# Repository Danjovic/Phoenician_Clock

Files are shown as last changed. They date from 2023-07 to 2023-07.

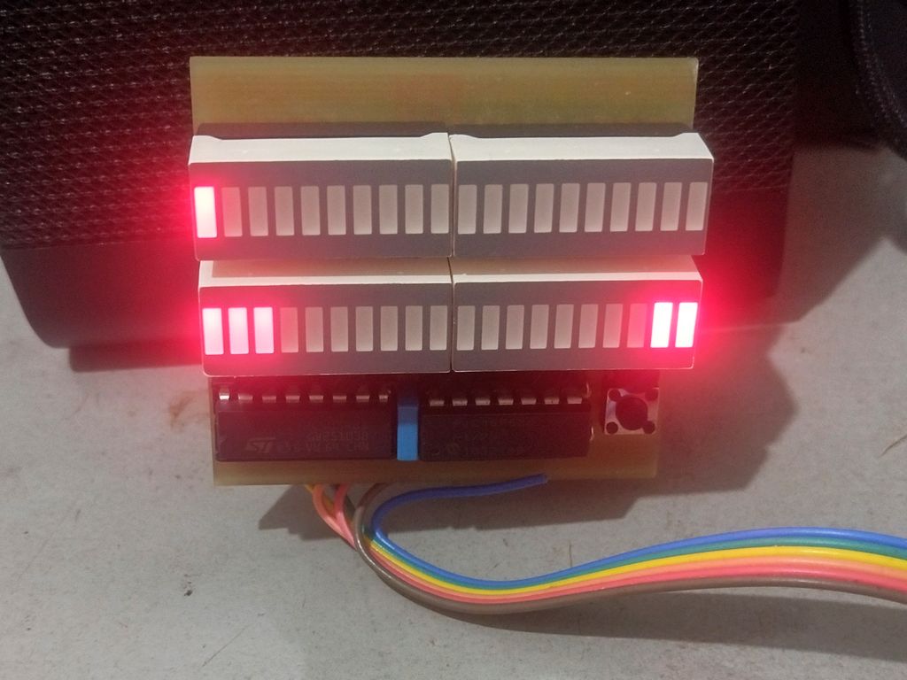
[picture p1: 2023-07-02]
doc/IMG_20230702_103354856_HDR.jpg

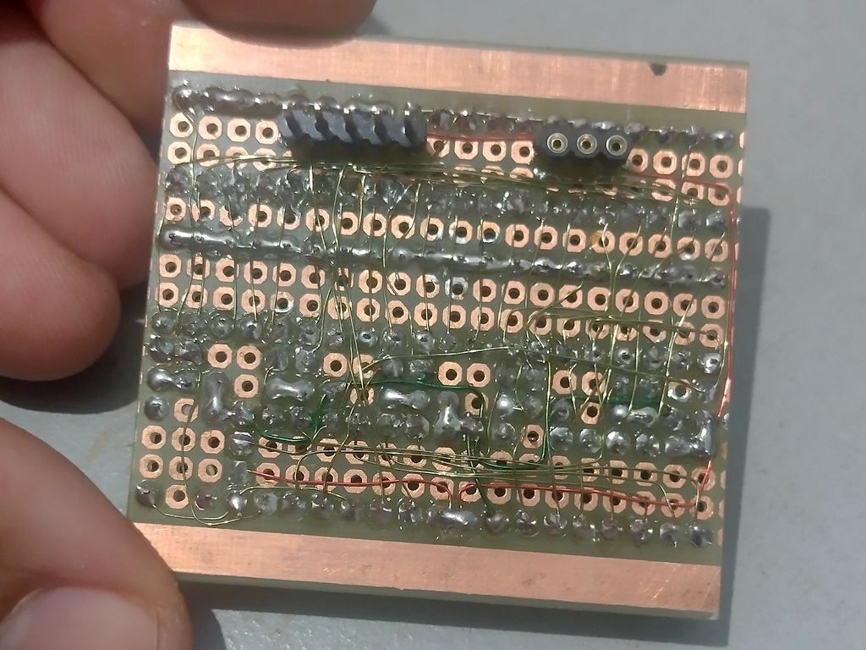
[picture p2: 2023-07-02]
doc/IMG_20230629_204115597.jpg

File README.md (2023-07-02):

# Phoenician_Clock
Digital clock with a LED bargraph display using Phoenician notation for individual digits.

## Introduction
Eevery digit of the (decimal) is displayed as a sequence of lit/unlit bars equivalent to the phoenician representation of digits 1 to 9. 

| Decimal | Phoenician |
|:---:|:---:|
| 1 | \| |
| 2 | \|\| |
| 3 | \|\|\| |
| 4 | \| \|\|\| |
| 5 | \|\| \|\|\| |
| 6 |  \|\|\|  \|\|\| |
| 7 | \| \|\|\| \|\|\| |
| 8 | \|\| \|\|\| \|\|\| |
| 9 | \|\|\| \|\|\| \|\|\| |

#### Dealing wiht the zero

The Phoenicians do not have a zero but it can be displayed as no segment lit. It is necessary, though, to justify the digits to the left or to the right to differentiate 10 from 01

| minute | Display |
|:---:|:---:|
| 05 | --------------\|\| \|\|\| |
| 50 | \|\| \|\|\|-------------- |

### How many bars ?
The biggest number to be displayed is 59. It takes at least 19 bars, being 6 for the digit 5 and 11 bars for the digit 9 plus two bars of spacing.
  
\|\|-\|\|\|--\|\|\|-\|\|\|-\|\|\|   

A couple of 10 segment Bargraph modules will be enough to represent the time.

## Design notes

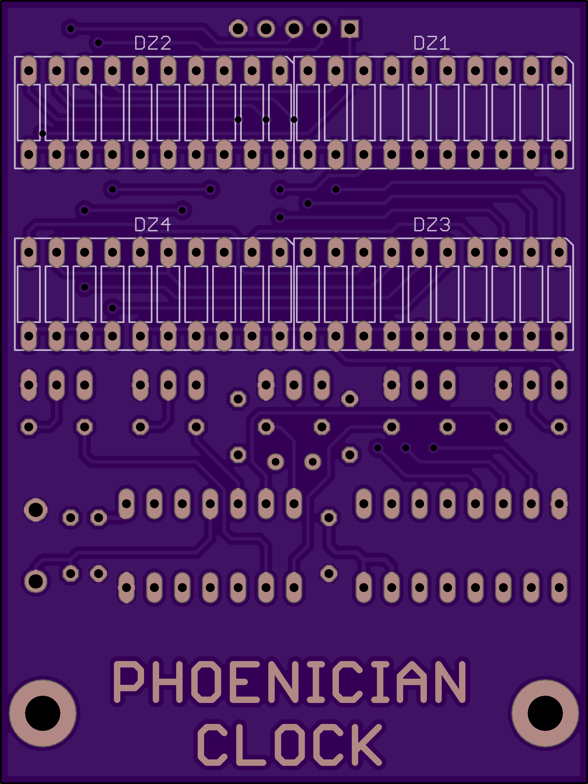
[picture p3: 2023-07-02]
doc/08815e3fb104f50b54aa8fa264df31f2.png

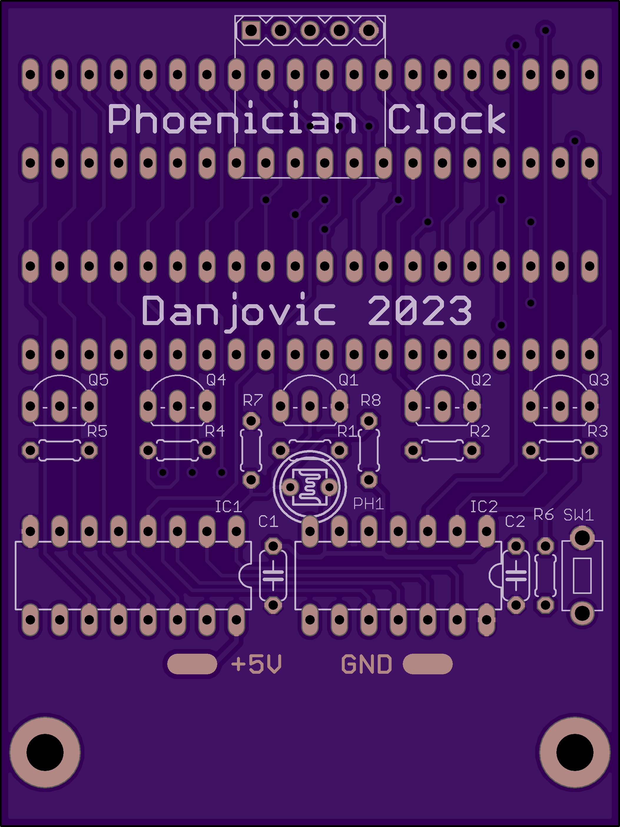
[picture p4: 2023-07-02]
doc/3a418aa845c536e2b2829bd620c7e151.png

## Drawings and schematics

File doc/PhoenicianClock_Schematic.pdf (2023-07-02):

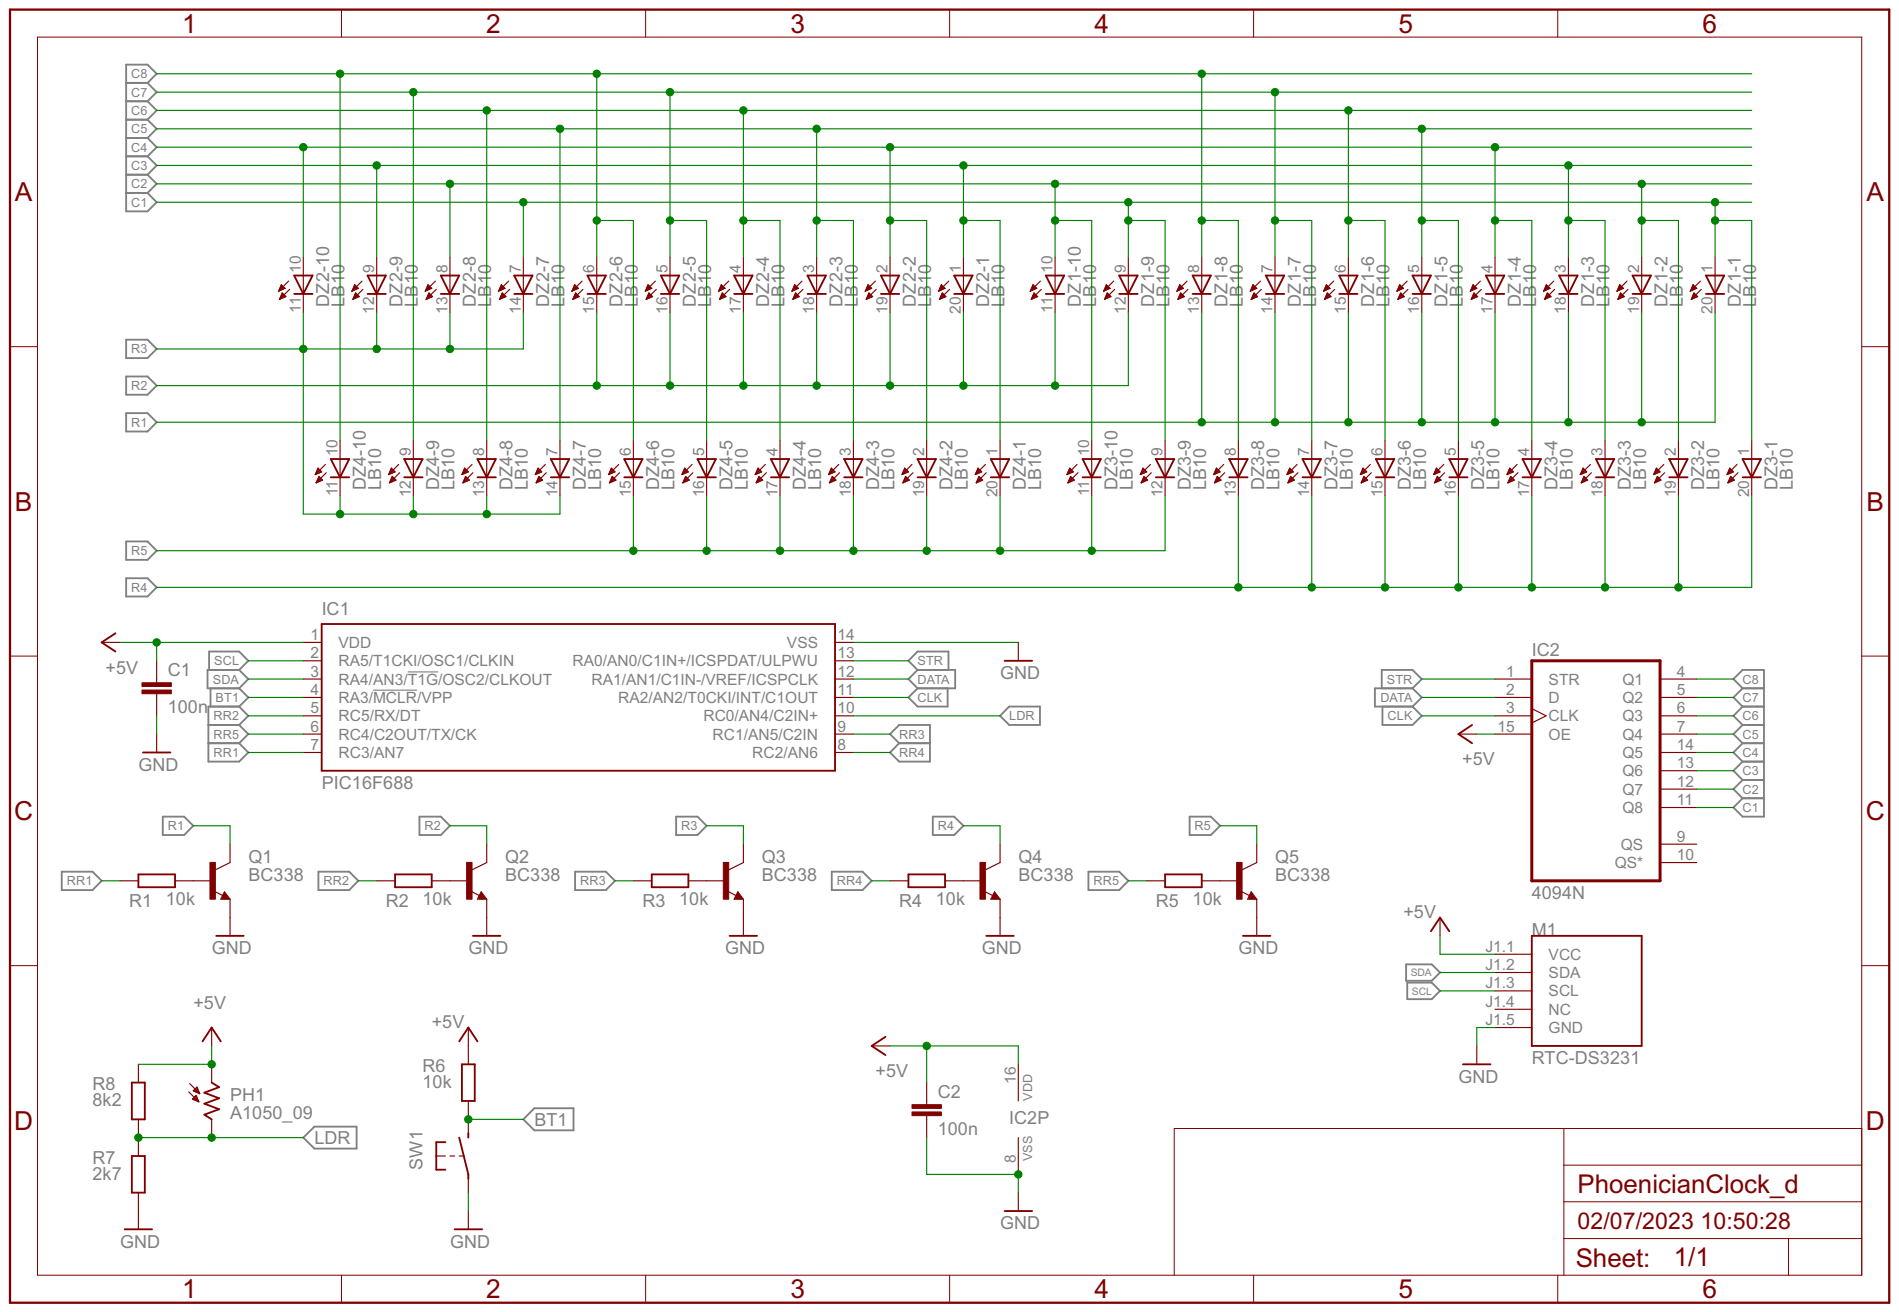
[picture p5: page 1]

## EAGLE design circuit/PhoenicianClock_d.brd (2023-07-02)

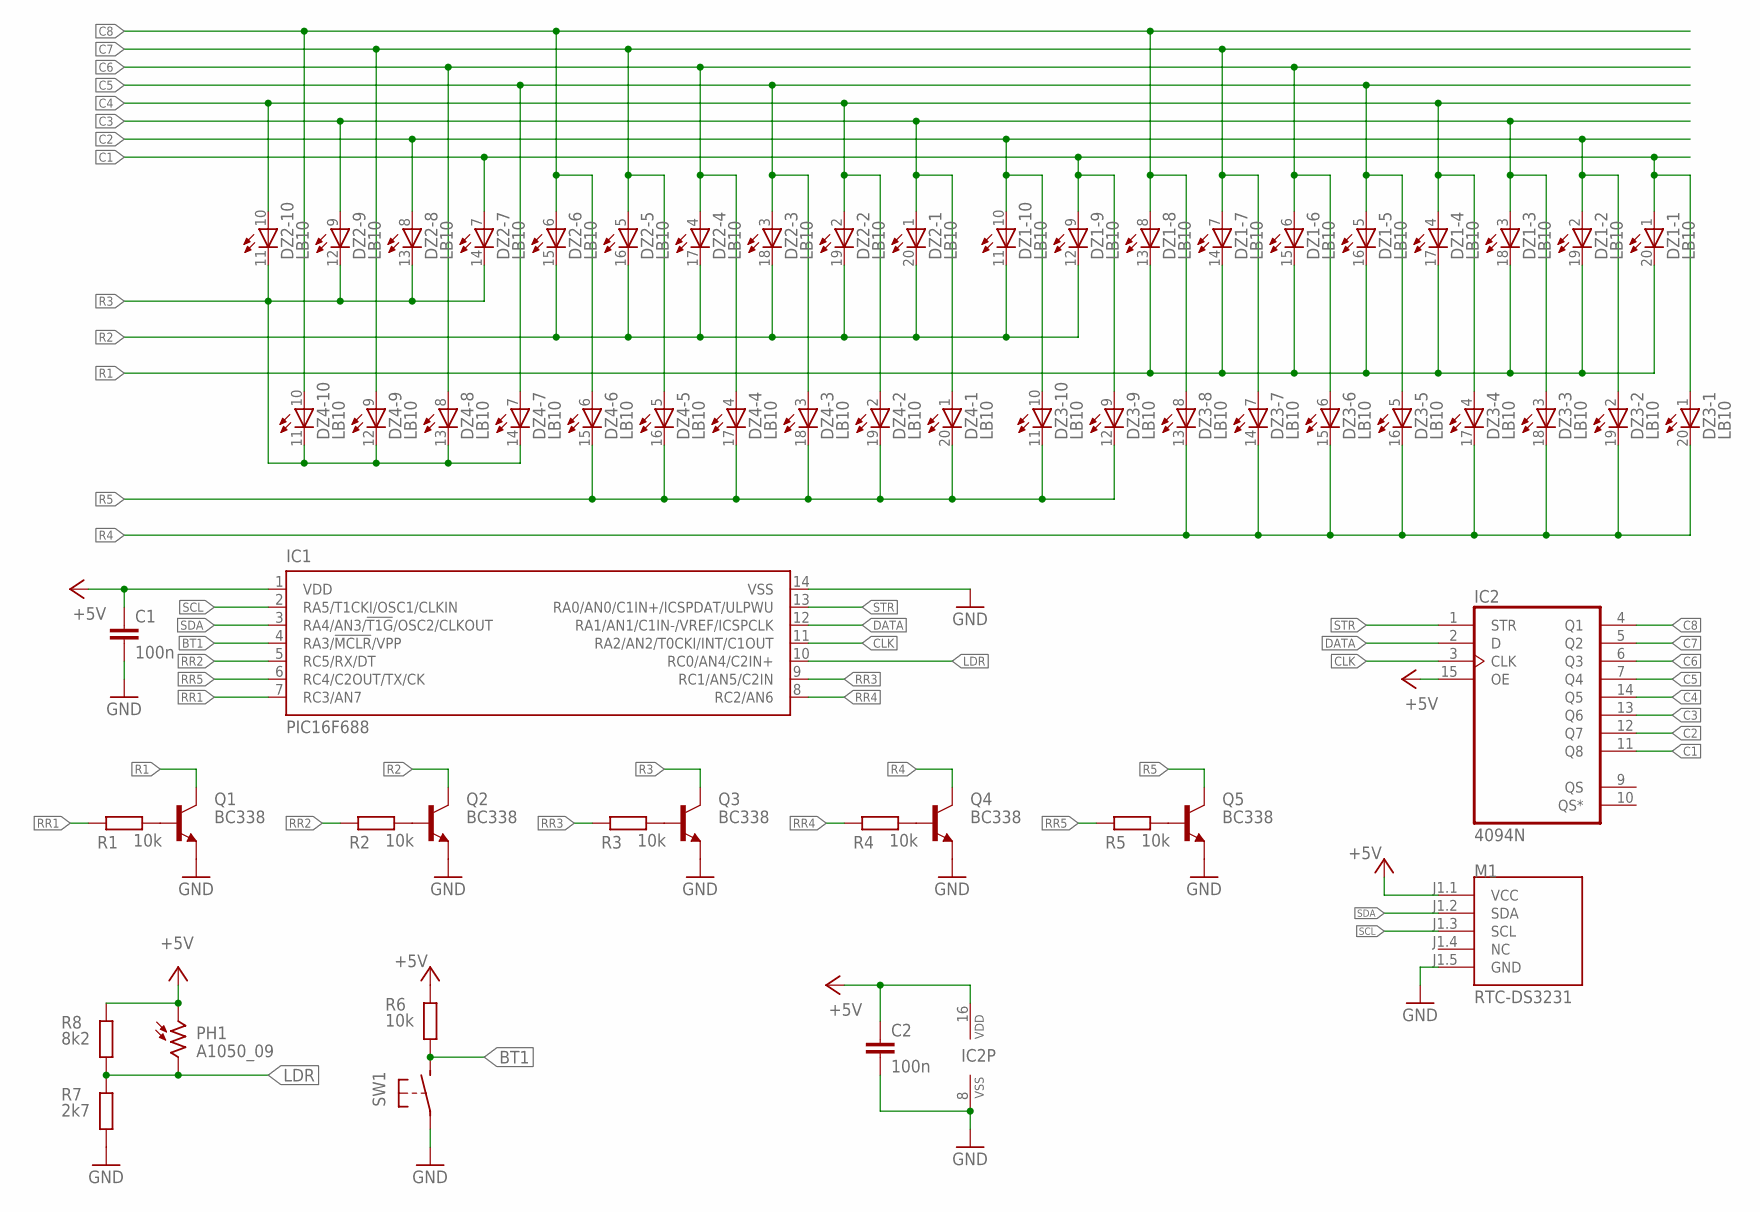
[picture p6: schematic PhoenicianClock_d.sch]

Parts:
C1, C2: 100n; C050-024X044
DZ1, DZ2, DZ3, DZ4: LB10
IC1: PIC16F688; DIL14
IC2: 4094N; DIL16
M1: RTC-DS3231; RTC-DS3231_SMALL
PH1: A1050_09; T0-46-A10XX
Q1, Q2, Q3, Q4, Q5: BC338; TO92-EBC
R1, R2, R3, R4, R5, R6: 10k; 0204/5
R7: 2k7; 0204/5
R8: 8k2; 0204/5
SW1: MINISPDT; 2PST_MINI

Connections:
+5V: C1.1, C2.1, IC1.1 (VDD), IC2.15 (OE), IC2.16 (VDD), M1.J1.1 (VCC), PH1.1, R6.2, R8.2
BT1: IC1.4 (RA3/!MCLR!/VPP), R6.1, SW1.P$2 (S)
C1: DZ1.1 (A), DZ1.9 (A), DZ2.7 (A), DZ3.1 (A), DZ3.9 (A), IC2.11 (Q8)
C2: DZ1.2 (A), DZ1.10 (A), DZ2.8 (A), DZ3.2 (A), DZ3.10 (A), IC2.12 (Q7)
C3: DZ1.3 (A), DZ2.1 (A), DZ2.9 (A), DZ3.3 (A), DZ4.1 (A), IC2.13 (Q6)
C4: DZ1.4 (A), DZ2.2 (A), DZ2.10 (A), DZ3.4 (A), DZ4.2 (A), IC2.14 (Q5)
C5: DZ1.5 (A), DZ2.3 (A), DZ3.5 (A), DZ4.3 (A), DZ4.7 (A), IC2.7 (Q4)
C6: DZ1.6 (A), DZ2.4 (A), DZ3.6 (A), DZ4.4 (A), DZ4.8 (A), IC2.6 (Q3)
C7: DZ1.7 (A), DZ2.5 (A), DZ3.7 (A), DZ4.5 (A), DZ4.9 (A), IC2.5 (Q2)
C8: DZ1.8 (A), DZ2.6 (A), DZ3.8 (A), DZ4.6 (A), DZ4.10 (A), IC2.4 (Q1)
CLK: IC1.11 (RA2/AN2/T0CKI/INT/C1OUT), IC2.3 (CLK)
DATA: IC1.12 (RA1/AN1/C1IN-/VREF/ICSPCLK), IC2.2 (D)
GND: C1.2, C2.2, IC1.14 (VSS), IC2.8 (VSS), M1.J1.5 (GND), Q1.E, Q2.E, Q3.E, Q4.E, Q5.E, R7.1, SW1.P$1
LDR: IC1.10 (RC0/AN4/C2IN+), PH1.2, R7.2, R8.1
unnamed: Q1.B, R1.2
unnamed: Q2.B, R2.2
unnamed: Q3.B, R3.2
unnamed: Q4.B, R4.2
unnamed: Q5.B, R5.2
R1: DZ1.13 (C), DZ1.14 (C), DZ1.15 (C), DZ1.16 (C), DZ1.17 (C), DZ1.18 (C), DZ1.19 (C), DZ1.20 (C), Q1.C
R2: DZ1.11 (C), DZ1.12 (C), DZ2.15 (C), DZ2.16 (C), DZ2.17 (C), DZ2.18 (C), DZ2.19 (C), DZ2.20 (C), Q2.C
R3: DZ2.11 (C), DZ2.12 (C), DZ2.13 (C), DZ2.14 (C), DZ4.11 (C), DZ4.12 (C), DZ4.13 (C), DZ4.14 (C), Q3.C
R4: DZ3.13 (C), DZ3.14 (C), DZ3.15 (C), DZ3.16 (C), DZ3.17 (C), DZ3.18 (C), DZ3.19 (C), DZ3.20 (C), Q4.C
R5: DZ3.11 (C), DZ3.12 (C), DZ4.15 (C), DZ4.16 (C), DZ4.17 (C), DZ4.18 (C), DZ4.19 (C), DZ4.20 (C), Q5.C
RR1: IC1.7 (RC3/AN7), R1.1
RR2: IC1.5 (RC5/RX/DT), R2.1
RR3: IC1.9 (RC1/AN5/C2IN), R3.1
RR4: IC1.8 (RC2/AN6), R4.1
RR5: IC1.6 (RC4/C2OUT/TX/CK), R5.1
SCL: IC1.2 (RA5/T1CKI/OSC1/CLKIN), M1.J1.3 (SCL)
SDA: IC1.3 (RA4/AN3/!T1G!/OSC2/CLKOUT), M1.J1.2 (SDA)
STR: IC1.13 (RA0/AN0/C1IN+/ICSPDAT/ULPWU), IC2.1 (STR)

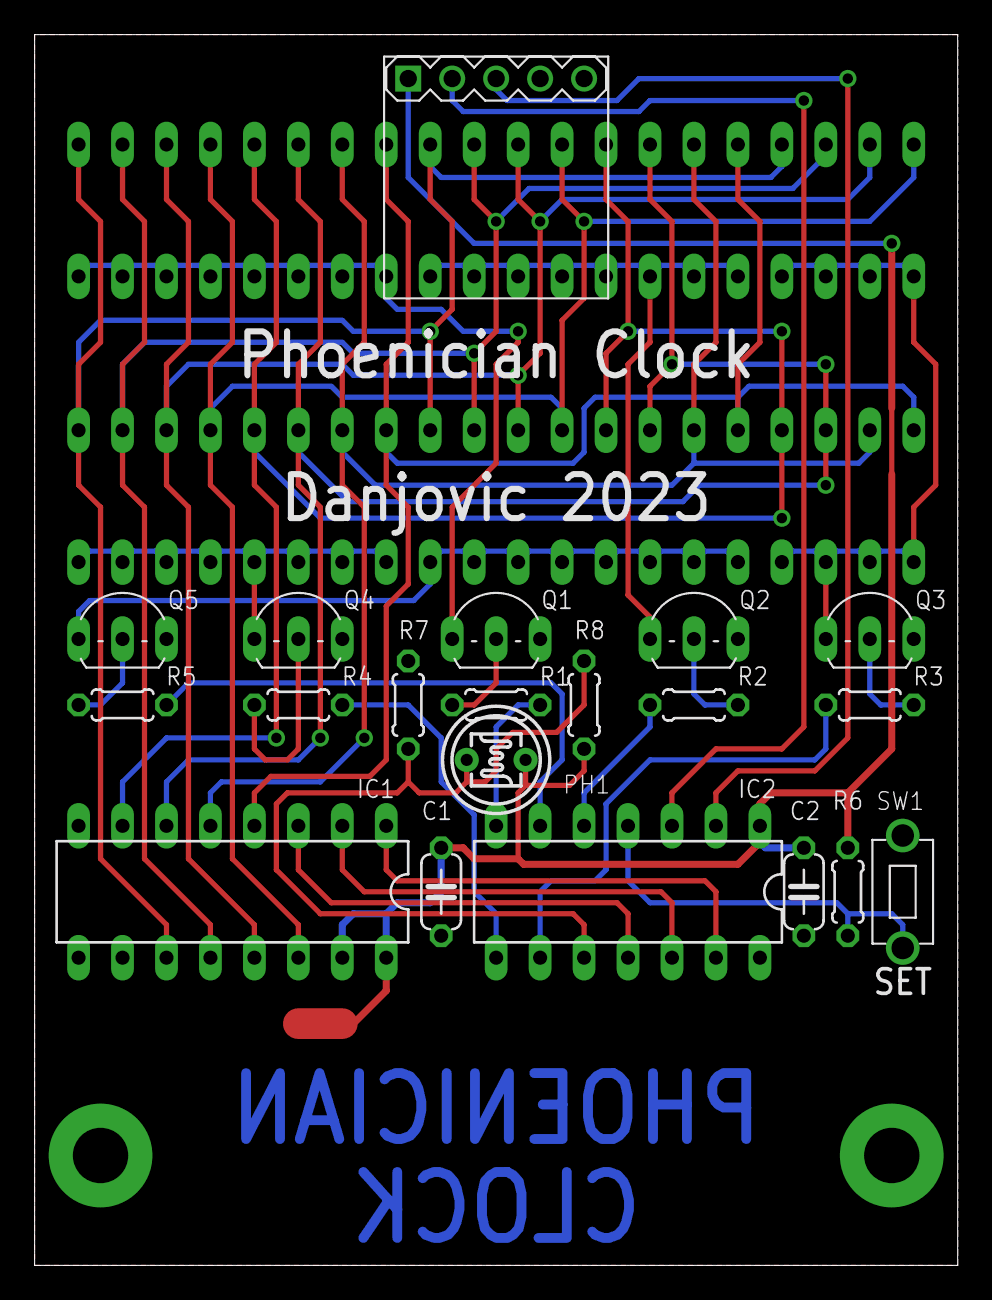
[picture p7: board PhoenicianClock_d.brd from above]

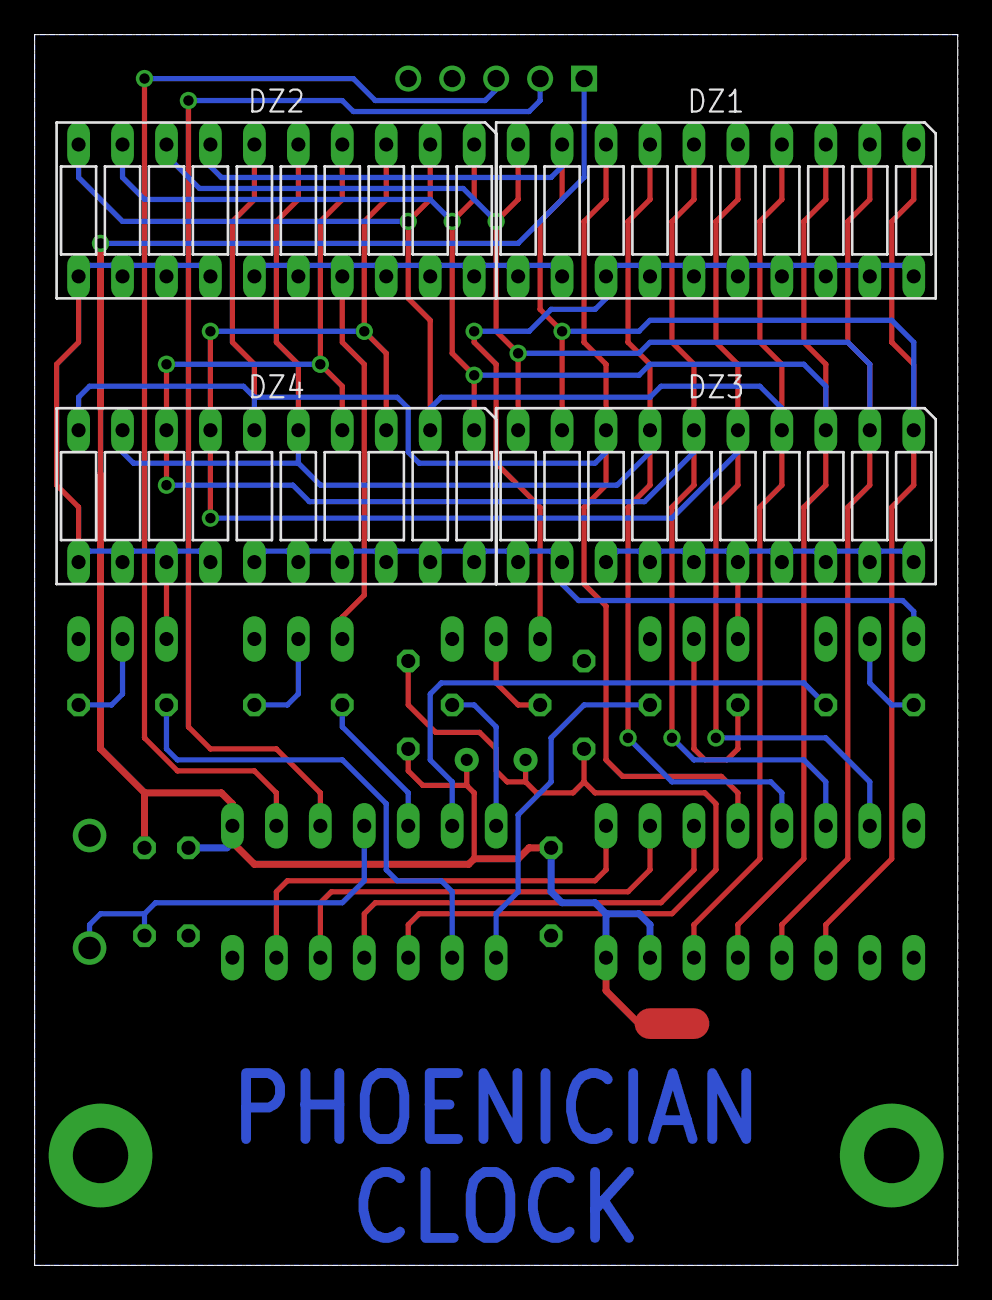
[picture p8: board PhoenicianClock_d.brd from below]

Board: 2 copper layers, 53.3 x 71.1 mm, 24 parts (4 on the bottom side), 32 nets.

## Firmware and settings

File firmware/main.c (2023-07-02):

/***
 *    $$$$$$$\  $$\                           $$\           $$\                     
 *    $$  __$$\ $$ |                          \__|          \__|                    
 *    $$ |  $$ |$$$$$$$\   $$$$$$\  $$$$$$$\  $$\  $$$$$$$\ $$\  $$$$$$\  $$$$$$$\  
 *    $$$$$$$  |$$  __$$\ $$  __$$\ $$  __$$\ $$ |$$  _____|$$ | \____$$\ $$  __$$\ 
 *    $$  ____/ $$ |  $$ |$$ /  $$ |$$ |  $$ |$$ |$$ /      $$ | $$$$$$$ |$$ |  $$ |
 *    $$ |      $$ |  $$ |$$ |  $$ |$$ |  $$ |$$ |$$ |      $$ |$$  __$$ |$$ |  $$ |
 *    $$ |      $$ |  $$ |\$$$$$$  |$$ |  $$ |$$ |\$$$$$$$\ $$ |\$$$$$$$ |$$ |  $$ |
 *    \__|      \__|  \__| \______/ \__|  \__|\__| \_______|\__| \_______|\__|  \__|
 *                                                                                  
 *                                                                                  
 *                                                                                  
 *     $$$$$$\  $$\                     $$\                                         
 *    $$  __$$\ $$ |                    $$ |                                        
 *    $$ /  \__|$$ | $$$$$$\   $$$$$$$\ $$ |  $$\                                   
 *    $$ |      $$ |$$  __$$\ $$  _____|$$ | $$  |                                  
 *    $$ |      $$ |$$ /  $$ |$$ /      $$$$$$  /                                   
 *    $$ |  $$\ $$ |$$ |  $$ |$$ |      $$  _$$<                                    
 *    \$$$$$$  |$$ |\$$$$$$  |\$$$$$$$\ $$ | \$$\                                   
 *     \______/ \__| \______/  \_______|\__|  \__|                                  
 *                                                                                  
 *                                                                                  
 *                                                                                  
 */


//         _               _   
//    _ __(_)_ _  ___ _  _| |_ 
//   | '_ \ | ' \/ _ \ || |  _|
//   | .__/_|_||_\___/\_,_|\__|
//   |_|                       

/*
   PIC16F688
                 +--___--+ 
           +5V --|1    14|-- GND                          
       SCL RA5 --|2    13|-- RA0 STROBE   |    
       SDA RA4 --|3    12|-- RA1 DOUT     | shif register
 (set) BT1 RA3 --|4    11|-- RA2 CLOCK    |   
       RR2 RC5 --|5    10|-- RC0 LDR (analog ch#4)
       RR5 RC4 --|6     9|-- RC1 RR3                  
       RR1 RC3 --|7     8|-- RC2 RR4     
                 +-------+  
*/

/*
   Display organization:
 
    40 LEDS: 
      20 on top row -> hours         20..17 16...9 8....1
      20 on bottowm row -> minutes   40..37 36..29 28..21
	  less significative bit on the right
 
   segment |disp[2]|    disp[1]    |     disp[0]   |  segment
     20    |3.2.1.0|7.6.5.4.3.2.1.0|7.6.5.4.3.2.1.0|  1
     40    |7.6.5.4|7.6.5.4.3.2.1.0|7.6.5.4.3.2.1.0|  21
           |disp[2]|    disp[4]    |     disp[3]   |
	  
   
	
   Display variable with 5 bytes 
   Element     bit  7  6  5  4  3  2  1  0 
   display[0] LED:  8  6  5  4  3  2  1  0
   display[1] LED: 16 15 14 13 12 11 10  9    
   display[2] LED: 40 39 38 37 20 19 18 17  -> Attention!
   display[3] LED: 28 27 26 25 24 23 22 21  
   display[4] LED: 36 45 34 33 32 31 30 29  

*/




//    _ _ _                 _        
//   | (_) |__ _ _ __ _ _ _(_)___ ___
//   | | | '_ \ '_/ _` | '_| / -_|_-<
//   |_|_|_.__/_| \__,_|_| |_\___/__/
//                                   


#include <pic16f688.h>
#include <stdint.h>
#include <stdbool.h>

// Fuse setting 
uint16_t __at _CONFIG configWord = _INTRC_OSC_NOCLKOUT & _CPD_OFF &  _CP_OFF &  _MCLRE_OFF & _WDT_OFF & _PWRTE_ON; // watchdog off



//       _      __ _      _ _   _             
//    __| |___ / _(_)_ _ (_) |_(_)___ _ _  ___
//   / _` / -_)  _| | ' \| |  _| / _ \ ' \(_-<
//   \__,_\___|_| |_|_||_|_|\__|_\___/_||_/__/
//                                            

#define LO 0
#define HI 1
#define OUT 0
#define INP 1
#define OFF 0
#define ON  1

// I2C Stuff
#define SDA  RA4
#define SCL  RA5
#define sendACK     true
#define sendNACK    false
#define RTC_ADDRESS 0x68

#define DIR_SDA TRISA4
#define DIR_SCL TRISA5

// Shift Register Stuff
#define STROBE RA0
#define DOUT   RA1
#define CLOCK  RA2

// Display Columns
#define RR1 RC3
#define RR2 RC5
#define RR3 RC1
#define RR4 RC2
#define RR5 RC4

// Buttons Stuff
#define btnSET RA3
#define th_SHORT_PRESS 3    // time thresholds
#define th_LONG_PRESS 25   // in units of 20ms

//
//    _ __  __ _ __ _ _ ___ ___
//   | '  \/ _` / _| '_/ _ (_-<
//   |_|_|_\__,_\__|_| \___/__/
//

// I2C related
#define sclHigh()   do { DIR_SCL = INP;  SCL = 1; } while (0)
#define sclLow()    do { DIR_SCL = OUT;  SCL = 0; } while (0)
#define sdaHigh()   do { DIR_SDA = INP;  SDA = 1; } while (0)
#define sdaLow()    do { DIR_SDA = OUT;  SDA = 0; } while (0)
#define sdaGet()    SDA 
#define I2Cdelay()  do {for (uint8_t i=1;i>0;i--) __asm__ ("nop\n\t"); } while (0)

// Button Related
#define btnSetPress()  (btnSET ==0)  

// Display Related
#define rowsOff() do { RR1 = OFF; RR2 = OFF; RR3 = OFF; RR4 = OFF; RR5 = OFF; } while (0)
#define row1on()  do { RR1 = ON ; RR2 = OFF; RR3 = OFF; RR4 = OFF; RR5 = OFF; } while (0)
#define row2on()  do { RR1 = OFF; RR2 = ON ; RR3 = OFF; RR4 = OFF; RR5 = OFF; } while (0)
#define row3on()  do { RR1 = OFF; RR2 = OFF; RR3 = ON ; RR4 = OFF; RR5 = OFF; } while (0)
#define row4on()  do { RR1 = OFF; RR2 = OFF; RR3 = OFF; RR4 = ON ; RR5 = OFF; } while (0)
#define row5on()  do { RR1 = OFF; RR2 = OFF; RR3 = OFF; RR4 = OFF; RR5 = ON ; } while (0)  

                     


//               _               _
//    __ _  _ __| |_ ___ _ __   | |_ _  _ _ __  ___ ___
//   / _| || (_-<  _/ _ \ '  \  |  _| || | '_ \/ -_|_-<
//   \__|\_,_/__/\__\___/_|_|_|  \__|\_, | .__/\___/__/
//                                   |__/|_|

typedef struct {
  unsigned units : 4;
  unsigned tens  : 3;
  unsigned       : 1;
} t_seconds;

typedef struct {
  unsigned units : 4;
  unsigned tens  : 3;
  unsigned       : 1;
} t_minutes;

typedef struct {
  unsigned units   : 4 ;
  unsigned tens    : 2 ;
  unsigned op12_24 : 1 ;
  unsigned         : 1 ;
} t_hours;

typedef struct {
  unsigned dow     : 3 ;  // day of week
  unsigned         : 5 ;
} t_wkDays;

typedef struct {
  unsigned units : 4;
  unsigned tens  : 2;
  unsigned       : 2;
} t_dates;

typedef struct {
  unsigned units   : 4 ;
  unsigned tens    : 1 ;
  unsigned         : 2 ;
  unsigned century : 1 ;
} t_monthsCty;

typedef struct {
  unsigned units : 4;
  unsigned tens  : 4;
} t_years;


typedef struct {
  t_seconds    seconds ;
  t_seconds    minutes ;
  t_hours        hours ;
  t_wkDays       wkDay ;
  t_dates         date ;
  t_monthsCty monthCty ;
  t_years         year ;
} t_timeAndDate;

typedef union  {
  uint8_t rawdata[7];
  t_timeAndDate datetime;
} t_ds3231records;


typedef enum   {
  ST_SHOW_TIME,
  ST_SET_HOUR,
  ST_SET_MINUTE
} t_operatingStates;

typedef enum   {
  BT_NONE,
  BT_SET,
  BT_BOTH
} t_buttonStates;


typedef enum   {
  EV_NOCHANGE,
  EV_SET_PULSE,
  EV_SET_LONG,
  EV_RELEASE
} t_buttonEvents;


//                   _            _
//    __ ___ _ _  __| |_ __ _ _ _| |_ ___
//   / _/ _ \ ' \(_-<  _/ _` | ' \  _(_-<
//   \__\___/_||_/__/\__\__,_|_||_\__/__/
//



//                 _      _    _        
//   __ ____ _ _ _(_)__ _| |__| |___ ___
//   \ V / _` | '_| / _` | '_ \ / -_|_-<
//    \_/\__,_|_| |_\__,_|_.__/_\___/__/
//                                      

t_ds3231records rtc;
volatile bool readyToGo = false;
t_operatingStates operatingState = ST_SHOW_TIME;

uint8_t display[5] ; 
volatile uint8_t tOFF = 32;
volatile bool blink = 0;

bool timeChanged = false;


uint8_t __TEMP_ADC;   // TODO REMOVE!!



//                 _       _
//    _ __ _ _ ___| |_ ___| |_ _  _ _ __  ___ ___
//   | '_ \ '_/ _ \  _/ _ \  _| || | '_ \/ -_|_-<
//   | .__/_| \___/\__\___/\__|\_, | .__/\___/__/
//   |_|                       |__/|_|

void _delay_ms(uint16_t ms);
inline void initHardware(void);

bool writeRtc (void); // t_ds3231records *t);
bool readRtc (void); // t_ds3231records *t);

void runClockEngine( t_buttonEvents btEvent );
void runDisplayEngine( void );
void runBrightnessControl ( void );
void runDisplayError( void );
t_buttonEvents buttonEvents (void) ;

//    _     _                         _      
//   (_)_ _| |_ ___ _ _ _ _ _  _ _ __| |_ ___
//   | | ' \  _/ -_) '_| '_| || | '_ \  _(_-<
//   |_|_||_\__\___|_| |_|  \_,_| .__/\__/__/
//                              |_|          
	
static void irqHandler(void) __interrupt 0 {
	// gets here every TMR0 
	static uint8_t tickCounter=0;
	static uint8_t digit=0;
    uint8_t i,j;


	// gets here every TMR0 int (every 256 ticks -> 128us) 
  
    tickCounter++;
    tickCounter &= 31;    // further division by 32 -> 4.096ms 
	if (tickCounter == 0) {
    
    
        rowsOff();
        // update column data
        j = display[digit];
        for (i=0;i<8;i++) {
            if ( j & 1) DOUT = 1;  else DOUT = 0;
            j>>=1;              
            CLOCK=1;
            CLOCK=0;
        }
        STROBE = 1;
        STROBE = 0;
     
       	// activate current row
        switch (digit) {
			case 0: // 
				row1on();
				break;
			   
			case 1: // 
				row2on(); 
				break;

			case 2: // 
				row3on();
				break;

			case 3: // 
				row4on(); 
				break;

			case 4: // 
				row5on(); 
				break;

        } // end switch
        
        if (++digit > 4) {
			digit = 0;
            readyToGo = 1;                        // main tick every 20.48 ms 
	    }
    } else if (tickCounter == tOFF ) {   // rudimentary PWM
		rowsOff();
    }	

	T0IF = 0;
}

//               _      
//    _ __  __ _(_)_ _  
//   | '  \/ _` | | ' \ 
//   |_|_|_\__,_|_|_||_|
//                      


void main (void)
{
    initHardware();

	if ( !readRtc() ) { // test RTC reading  at the beginning, initialize some values if failed
           rtc.rawdata[0] = 0x00; // 00 Seconds
           rtc.rawdata[1] = 0x23; // 23 Minutes
           rtc.rawdata[2] = 0x23; // 23 Hours (in 24 hr format)
           rtc.rawdata[3] = 0x04; // 04 Day of week
           rtc.rawdata[4] = 0x23; // 23 Day of Month
           rtc.rawdata[5] = 0x04; // 04 Month (+ century=0)
           rtc.rawdata[6] = 0x23; // 23 Year
		}

   
  
   
   
   
   
   
   

    for (;;) { 
		while (!readyToGo); // wait for 16ms flag
		readyToGo=0;        // reset go flag 
   
        runBrightnessControl ();
     //   display[0] = tOFF;
        
     //   display[3] = __TEMP_ADC;
        
    
  

        if ( readRtc ( )  ) {
            runDisplayEngine();        
            runClockEngine( buttonEvents () );
            if (timeChanged) {    // TODO check for error during write to RTC
                writeRtc ( );
                timeChanged = false;
            }  
        } else { 
            runDisplayError();
        } 
        
       
        
    } // for (;;)
    
  
    
    
    

} // main




//     __              _   _             
//    / _|_  _ _ _  __| |_(_)___ _ _  ___
//   |  _| || | ' \/ _|  _| / _ \ ' \(_-<
//   |_|  \_,_|_||_\__|\__|_\___/_||_/__/
//                                       

// ******************************************************************************************************************
//
// Hardware Initialization
//
inline void initHardware(void) {

   // Initialize clock
   IRCF0 = 1 ;  // 8MHz -> IRCF[2..0] = 111 ( default 110 on startup )
   
   // Initialize I/O ports
   CMCON0 = ( _CM2 | _CM1 | _CM0); // analog comparators off, pins as I/O 
   ANSEL = 0;

   
      
   TRISC=0b00000001; // RC0 as input (LDR), other pins as outputs (rows) 
   PORTC=0b00000000; // all digits unactive
    
   TRISA=0b11111000; // RA0,RA1,RA2 as outputs, other pins as inputs 
   PORTA=0b00000000; // All low   
   WPUA4 = 1;  // pullups on i2c signals
   WPUA5 = 1;
   

   // Initialize A/D converter
   ANSEL = (1<<4); // Configure analog/digital I/O (ANSEL)
   ADCON0 = 0b00010000; // CHS[2..0] = 100 -> Channel AN4 (@pin RC0)
   ADCON1 = 0b01110000;	 //  ADCS1 [2..0] = x11 -> FRC Internal 500KHz oscillator
   ADON = 1;
   GO_NOT_DONE = 1;   // Set GO/DONE bit to start conversions

   // Program Timer 0 interrupt every 256 instruction cycles 
   // IRQ occours at each 8000000/4/256 = 7812.5Hz
   // Display refresh at 7812.5Hz / 32 = 244.1Hz PWM
   // main program runs at 244.1/5 = 48.8Hz => ~20.5ms
   
   OPTION_REG = _PSA; 
   // _PSA       1 = Prescaler is assigned to the WDT (timer 0-> 1:1)
   //  _T0CS     0 = Internal instruction cycle clock 
   //  _NOT_RAPU 0 = PORTA pull-ups enabled by port latch values
 
	TMR0  = 0;  // clear timer 0 counter
	T0IF  = 0;  // clear any pending timer 0 flag
    T0IE  = 1;  // enable timer 0 interrupts
    GIE   = 1;  // enable global interrupts
 

}


// ******************************************************************************************************************
//
// Soft I2C
//

void I2Cstart() {
  sdaHigh(); I2Cdelay();
  sclHigh(); I2Cdelay(); // sda = 1;  scl = 1;
  sdaLow();  I2Cdelay(); // sda = 0;
  sclLow();
}
//

void I2Cstop() {
  sdaLow();  I2Cdelay(); // sda = 0;  sda = 0;
  sclHigh(); I2Cdelay(); // scl = 1;  scl = 1;
  sdaHigh();             // sda = 1;
}
//

bool I2Cwrite(uint8_t d) {
  uint8_t i;
  bool nack;
  for (i = 0; i < 8; i++) {
    if (d & 0x80)   // write data bit, msb first
      sdaHigh();
    else 
      sdaLow();
    I2Cdelay(); // give time to settle data
    sclHigh(); I2Cdelay();  sclLow(); // pulse clock
    d = d << 1; // next bit
  }
  // now get the ack
  sdaHigh(); I2Cdelay();  // release data line
  sclHigh(); I2Cdelay();  // release clock line
  nack = sdaGet();  // get nack bit
  sclLow();// clock low
  return nack;
}
//

uint8_t I2Cread(bool nack) {
  uint8_t i, d;

  d = 0;
  sdaHigh();             // release data line and
  sclLow(); I2Cdelay();  // pull down clock line and wait to write a bit
  for (i = 0; i < 8; i++)  {
    sclHigh(); I2Cdelay(); // release clock line to read the data
    d = d << 1;
    if (sdaGet() ) d |= 1; // read data bit, msb first
    sclLow(); I2Cdelay();  // pull clock down to allow next bit
  }
  // give ACK / NACK
  if ( nack ) sdaLow(); else sdaHigh();

  sclHigh(); I2Cdelay(); // Pulse clock
  sclLow(); I2Cdelay();  //

  sdaHigh(); // release the data line
  return d;
}
//

// ******************************************************************************************************************
//
// RTC chip handling
//

// write time data on clock Chip using I2C
bool writeRtc ( void) {
  uint8_t i;
  I2Cstart();
  if (!I2Cwrite((uint8_t)(RTC_ADDRESS << 1)) ) {
    I2Cwrite( 0x00 ); // register address, 1st clock register
    for ( i = 0 ; i < 7 ; i++)
      I2Cwrite(rtc.rawdata[i]);
    I2Cstop();
    return true;
  } else {
    I2Cstop(); I2Cstop();
  } return false;
}
//

// read time data from clock Chip using I2C
bool readRtc ( void ) {
  uint8_t i;
  I2Cstart();
  if ( !I2Cwrite((uint8_t)(RTC_ADDRESS << 1)) ) {
    I2Cwrite( 0x00); // register address, 1st clock register
    I2Cstart();  // repeated start
    I2Cwrite((uint8_t)(RTC_ADDRESS << 1)  | 1);
    for ( i = 0 ; i < 6 ; i++) {
      rtc.rawdata[i] = I2Cread ( sendACK );
    }
    rtc.rawdata[i] = I2Cread ( sendNACK );       // NACK on last bit
    I2Cstop();
    return true;
  } else {
    I2Cstop(); I2Cstop();
  } return false;
}
//

void _delay_ms(uint16_t td) {
   uint16_t d = td;
   
   while (--d) {
     for (uint8_t i=100;i>0;i--)
     __asm__ ("nop\n\t");   
   }
}
 

// ******************************************************************************************************************
//
// Button handling
//
// Read Button press
t_buttonStates getButton (void) {

  bool btSet = btnSetPress();
  
  if ( btSet ) {    // SET press?
     return BT_SET;  // 
  } else return BT_NONE;
  
}
//

// Get button events - pulse, long press
t_buttonEvents buttonEvents (void) {
  static uint8_t btSetCount = 0;
  uint8_t btEvent = EV_NOCHANGE;
  uint8_t buttonNow = getButton();

  switch (buttonNow ) {

    case BT_SET:
      if ( btSetCount < th_LONG_PRESS ) {
        btSetCount++;                         // will stop count at threshold
        if ( btSetCount >= th_LONG_PRESS ) { // and generate an unique long press event
          btEvent  = EV_SET_LONG;
        }
      }
      break;


    case BT_NONE:
      if ( btSetCount >= th_SHORT_PRESS && btSetCount < th_LONG_PRESS ) {
        btEvent = EV_SET_PULSE;
      }

      btSetCount = 0;
      break;

    default:
      btEvent = EV_NOCHANGE;
      break;
  }
  return btEvent;
}
//



// ******************************************************************************************************************
//
// Date and Time calculation and handling stuff
//

// advance current hour
void advanceHour (void) {
	
  uint8_t d = ((1
                + 10 * (uint8_t)rtc.datetime.hours.tens
                + (uint8_t)rtc.datetime.hours.units )   ) % 24;

  rtc.datetime.hours.tens = ( (uint8_t) d / 10 )  & 0b00000011;
  rtc.datetime.hours.units = ( (uint8_t) d % 10 ) & 0b00001111;
  rtc.datetime.hours.op12_24 = 0; // force 24 hour mode
  timeChanged = true; // update rtc data
  //writeRtc();

}
//

// advance current minute
void advanceMinute (void) {
  uint8_t d = (1
               + 10 * (uint8_t)rtc.datetime.minutes.tens
               + (uint8_t)rtc.datetime.minutes.units ) % 60;

  rtc.datetime.minutes.tens = ( (uint8_t) d / 10 )  & 0b00000111;
  rtc.datetime.minutes.units = ( (uint8_t) d % 10 ) & 0b00001111;
  rtc.datetime.hours.op12_24 = 0; // force 24 hour mode
  timeChanged = true; // update rtc data
  //writeRtc();
}
//




// clock engine
void runClockEngine( t_buttonEvents btEvent ){

   switch ( operatingState ) {
    case ST_SHOW_TIME:
		if ( btEvent == EV_SET_LONG ) operatingState = ST_SET_HOUR;

	break;
	
    case ST_SET_HOUR:
		if ( btEvent == EV_SET_LONG )  operatingState = ST_SET_MINUTE;	
		if ( btEvent == EV_SET_PULSE ) advanceHour();	

	break;
	
    case ST_SET_MINUTE:
		if ( btEvent == EV_SET_LONG )  operatingState = ST_SHOW_TIME;	
		if ( btEvent == EV_SET_PULSE ) advanceMinute();	
	break;
	
   }
}




// Display engine
void runDisplayEngine( void ) {
  static uint8_t sequentialCounter = 0;
  uint8_t displayBuf[5];
  
  // fulfill display data with phoenician numerals
 
  switch ( rtc.datetime.hours.units ) { // units of hours
     case 9: displayBuf[1] = 0b00000111; displayBuf[0] = 0b01110111; break;  
     case 8: displayBuf[1] = 0b00000011; displayBuf[0] = 0b01110111; break;
     case 7: displayBuf[1] = 0b00000001; displayBuf[0] = 0b01110111; break; 
     case 6: displayBuf[1] = 0b00000000; displayBuf[0] = 0b01110111; break;
     case 5: displayBuf[1] = 0b00000000; displayBuf[0] = 0b00110111; break;
     case 4: displayBuf[1] = 0b00000000; displayBuf[0] = 0b00010111; break;
     case 3: displayBuf[1] = 0b00000000; displayBuf[0] = 0b00000111; break; 
     case 2: displayBuf[1] = 0b00000000; displayBuf[0] = 0b00000011; break;
     case 1: displayBuf[1] = 0b00000000; displayBuf[0] = 0b00000001; break;
     case 0:                                                         
	 default:displayBuf[1] = 0b00000000; displayBuf[0] = 0b00000000; break;
  }
	  
  switch ( rtc.datetime.hours.tens ) { // tens of hours
     case 2: displayBuf[2] = 0b00001100; break;
     case 1: displayBuf[2] = 0b00001000; break;
     case 0: 
	 default:displayBuf[2] = 0b00000000; break;
  }	  
  
  
  switch ( rtc.datetime.minutes.units ) { // units of minutes
     case 9: displayBuf[4] = 0b00000111; displayBuf[3] = 0b01110111; break;  
     case 8: displayBuf[4] = 0b00000011; displayBuf[3] = 0b01110111; break;
     case 7: displayBuf[4] = 0b00000001; displayBuf[3] = 0b01110111; break; 
     case 6: displayBuf[4] = 0b00000000; displayBuf[3] = 0b01110111; break;
     case 5: displayBuf[4] = 0b00000000; displayBuf[3] = 0b00110111; break;
     case 4: displayBuf[4] = 0b00000000; displayBuf[3] = 0b00010111; break;
     case 3: displayBuf[4] = 0b00000000; displayBuf[3] = 0b00000111; break; 
     case 2: displayBuf[4] = 0b00000000; displayBuf[3] = 0b00000011; break;
     case 1: displayBuf[4] = 0b00000000; displayBuf[3] = 0b00000001; break;
     case 0:                                                         
	 default:displayBuf[4] = 0b00000000; displayBuf[3] = 0b00000000; break;
  }  
  
  
  switch ( rtc.datetime.minutes.tens ) { // tens of minutes
     case 5: displayBuf[2] |= 0b11010000; displayBuf[4] |= 0b11000000; break;
     case 4: displayBuf[2] |= 0b10110000; displayBuf[4] |= 0b10000000; break;
     case 3: displayBuf[2] |= 0b11100000; displayBuf[4] |= 0b00000000; break; 
     case 2: displayBuf[2] |= 0b11000000; displayBuf[4] |= 0b00000000; break;
     case 1: displayBuf[2] |= 0b10000000; displayBuf[4] |= 0b00000000; break;
     case 0:                                                         
	 default:displayBuf[2] |= 0b00000000; displayBuf[4] |= 0b00000000; break;
  }	  
	  
	  
  // blank upper or lower segments when in time setup mopdes 
  if ( sequentialCounter > 10)  { // Display mode	  
	  if ( operatingState == ST_SET_HOUR) {
		  displayBuf[0] = 0;     // blank upper row of segments
		  displayBuf[1] = 0; 
		  displayBuf[2] &= 0xf0;
	  } else if ( operatingState == ST_SET_MINUTE){
		  displayBuf[2] &= 0x0f;   // blank lower row of segments
		  displayBuf[3] = 0; 
		  displayBuf[4] = 0;  
	  }
  }         
    
  sequentialCounter++; 
  if (sequentialCounter > 20 ) sequentialCounter = 0;  // ~200ms
 
  // update displays     
   display[0] = displayBuf[0];
   display[1] = displayBuf[1];
   display[2] = displayBuf[2];
   display[3] = displayBuf[3];
   display[4] = displayBuf[4];   

}
//
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

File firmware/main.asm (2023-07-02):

;--------------------------------------------------------
; File Created by SDCC : free open source ANSI-C Compiler
; Version 4.1.0 #12072 (MINGW64)
;--------------------------------------------------------
; PIC port for the 14-bit core
;--------------------------------------------------------
;	.file	"main.c"
	list	p=16f688
	radix dec
	include "p16f688.inc"
;--------------------------------------------------------
; config word(s)
;--------------------------------------------------------
	__config 0x3fc4
;--------------------------------------------------------
; external declarations
;--------------------------------------------------------
	extern	__divsint
	extern	__modsint
	extern	__mulint
	extern	_ADCON1
	extern	_ANSEL
	extern	_TRISC
	extern	_TRISA
	extern	_OPTION_REG
	extern	_ADCON0
	extern	_ADRESH
	extern	_CMCON0
	extern	_PORTC
	extern	_PORTA
	extern	_TMR0
	extern	_WPUbits
	extern	_OSCCONbits
	extern	_TRISAbits
	extern	_ADCON0bits
	extern	_INTCONbits
	extern	_PORTCbits
	extern	_PORTAbits
	extern	__sdcc_gsinit_startup
;--------------------------------------------------------
; global declarations
;--------------------------------------------------------
	global	_advanceMinute
	global	_advanceHour
	global	_getButton
	global	_I2Cread
	global	_I2Cwrite
	global	_I2Cstop
	global	_I2Cstart
	global	_main
	global	___TEMP_ADC
	global	_timeChanged
	global	_blink
	global	_tOFF
	global	_display
	global	_operatingState
	global	_readyToGo
	global	_rtc
	global	_initHardware
	global	_writeRtc
	global	_readRtc
	global	__delay_ms
	global	_buttonEvents
	global	_runClockEngine
	global	_runDisplayEngine
	global	_runBrightnessControl
	global	_runDisplayError

	global PSAVE
	global SSAVE
	global WSAVE
	global STK12
	global STK11
	global STK10
	global STK09
	global STK08
	global STK07
	global STK06
	global STK05
	global STK04
	global STK03
	global STK02
	global STK01
	global STK00

sharebank udata_ovr 0x0070
PSAVE	res 1
SSAVE	res 1
WSAVE	res 1
STK12	res 1
STK11	res 1
STK10	res 1
STK09	res 1
STK08	res 1
STK07	res 1
STK06	res 1
STK05	res 1
STK04	res 1
STK03	res 1
STK02	res 1
STK01	res 1
STK00	res 1

;--------------------------------------------------------
; global definitions
;--------------------------------------------------------
UD_main_0	udata
_rtc	res	7

UD_main_1	udata
_display	res	5

UD_main_2	udata
___TEMP_ADC	res	1

;--------------------------------------------------------
; absolute symbol definitions
;--------------------------------------------------------
;--------------------------------------------------------
; compiler-defined variables
;--------------------------------------------------------
UDL_main_0	udata
r0x103B	res	1
r0x103C	res	1
r0x103D	res	1
r0x103A	res	1
r0x102E	res	1
r0x102F	res	1
r0x1030	res	1
r0x1031	res	1
r0x1036	res	1
r0x1037	res	1
r0x1038	res	1
r0x1032	res	1
r0x1033	res	1
r0x1034	res	1
r0x1035	res	1
r0x102C	res	1
r0x102B	res	1
r0x102D	res	1
r0x1029	res	1
r0x102A	res	1
r0x1022	res	1
r0x1023	res	1
r0x1024	res	1
r0x1025	res	1
r0x1026	res	1
r0x1027	res	1
r0x1028	res	1
r0x1021	res	1
r0x101D	res	1
r0x101E	res	1
r0x101F	res	1
r0x1020	res	1
___sdcc_saved_fsr	res	1
_runDisplayEngine_displayBuf_65536_128	res	5
;--------------------------------------------------------
; initialized data
;--------------------------------------------------------

IDD_main_0	idata
_readyToGo
	db	0x00	;  0


IDD_main_1	idata
_operatingState
	db	0x00	; 0


IDD_main_2	idata
_tOFF
	db	0x20	; 32


IDD_main_3	idata
_blink
	db	0x00	;  0


IDD_main_4	idata
_timeChanged
	db	0x00	;  0


IDD_main_5	idata
_irqHandler_tickCounter_65536_11
	db	0x00	; 0


IDD_main_6	idata
_irqHandler_digit_65536_11
	db	0x00	; 0


IDD_main_7	idata
_buttonEvents_btSetCount_65536_115
	db	0x00	; 0


IDD_main_8	idata
_runDisplayEngine_sequentialCounter_65536_128
	db	0x00	; 0


IDD_main_9	idata
_runBrightnessControl_lighSenseCounter_65536_137
	db	0x00	; 0


IDD_main_10	idata
_runDisplayError_sequentialCounter_65536_141
	db	0x00	; 0
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
